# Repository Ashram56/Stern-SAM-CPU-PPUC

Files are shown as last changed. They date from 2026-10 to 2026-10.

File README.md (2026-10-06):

# Stern SAM CPU PPUC

A replacement CPU board for the Stern SAM pinball platform. A Raspberry Pi runs the original game ROM under PinMAME
through the [PPUC](https://github.com/PPUC) stack. An RP2354B on the same board drives the original IO power board bus (J1)
with its PIO, reads the switch matrix, dedicated switches and DIP switches, and can scan the original DMD.

- [docs/ARCHITECTURE.md](docs/ARCHITECTURE.md): architecture, bus timing, pin budget, safety, and open questions.
- [docs/reference/](docs/reference/): Stern SAM manual extracts (IO power driver and CPU/Sound board schematics, backbox,
  playfield, cabinet and coin door wiring).

Background:
- [Tron-Legacy-LE-ROM-Decryption/io/bus](https://github.com/Ashram56/Tron-Legacy-LE-ROM-Decryption/tree/main/io/bus):
  the CPU to IO board bus as the SAM ROM drives it.
- [Stern-SAM-Databus-Analysis](https://github.com/Ashram56/Stern-SAM-Databus-Analysis): J1 pinout and IO board schematic notes.

## Licence

- Firmware and software: GNU GPL v3 ([LICENSE](LICENSE)), matching PPUC.
- Hardware design files: CERN Open Hardware Licence v2, strongly reciprocal ([LICENSE-HARDWARE](LICENSE-HARDWARE)).
- The manual extracts in `docs/reference/` are Stern Pinball's material, kept for reference, and are not covered by
  either licence.

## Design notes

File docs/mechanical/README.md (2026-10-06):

# Original SAM CPU/Sound board: connector and mounting-hole positions

Mechanical reference for laying out the replacement board so it drops into
the original position in the backbox, reuses the original mounting screws,
and lets the existing harness plugs reach their headers.

Source: the component-layout page of the Stern manual
(`docs/reference/Stern_SAM_Manual-CPU_Sound_Board_Schematic.pdf`, page 11,
board 520-5246-00 **Rev G**). That page is a vector drawing, so positions
were read from its path data, not from a scan. `tools/sam_cpu_mechanical.py`
regenerates every file here.

| File | What it is |
|---|---|
| `sam_cpu_520-5246-00_positions.csv` | Every pin, connector body and hole, in mm |
| `sam_cpu_520-5246-00_outline.dxf` | Board edge, holes, connector bodies, pins (layers EDGE, HOLES, CONN, PINS) for import into KiCad |
| `sam_cpu_520-5246-00_annotated.png` | The layout page with the computed coordinates marked |

## Coordinate system

Millimetres, origin at the **top-left corner of the board**, X to the right,
Y down (KiCad convention), seen from the component side with the board as it
hangs in the backbox: J11 power at the top, switch connectors on the left
and bottom edges, USB/serial/display on the right. The DXF uses the same
origin with Y negated (DXF Y points up); import it with the origin at the
top-left corner.

## Scale and confidence

The drawing is uniformly scaled (round holes are round). The scale comes
from connector bodies whose length is fixed by their standard, and six
independent ones agree to within 0.05 %: J1, J2, J3 (n x 3.96 mm KK-396
bodies), J9 (2x10 box header, 33.02 mm), J5 (2x7 box header, 25.40 mm) and
J7 (2x10 pin field, 25.40 mm).

The result lands on round inch values, which is a good sign the scale is
right: the board comes out at **219.06 x 231.76 mm = 8.625 x 9.125 in**,
J9 pins sit at X = 10.16 / 12.70 mm (0.4 / 0.5 in), and every switch
connector pin falls on a 0.025 in grid.

| Quantity | Confidence |
|---|---|
| Board size, hole centres, pin positions **along** each connector | High, about ±0.3 mm (assuming your board matches Rev G) |
| Pin row **across** a KK-396 connector (X of J12/J6/J13, Y of J1/J2/J3) | Medium, ±0.8 mm: the drawing shows the housing, not the pins. I took the centre of the housing without its friction-ramp strip; the row is probably exactly 10.16 mm (0.4 in) from the board edge |
| Hole diameters | Low: the drawing shows the pad/keep-out shapes, not necessarily the drill |

## Mounting holes

Four keyhole slots in the corners plus four round holes. The keyholes open
**upward**: the board is hung on screws through the large circle and drops
down, so the screw shank ends at the top of the slot. That top-of-slot
centre is the screw position to match.

| Hole | Type | Screw X | Screw Y | Notes |
|---|---|---|---|---|
| MH6 | keyhole, top-left | 8.24 | 6.27 | clearance circle centre (8.24, 13.69), Ø10.4; slot 4.4 wide |
| MH1 | keyhole, top-right | 210.16 | 6.27 | circle centre (210.16, 13.69) |
| MH3 | keyhole, bottom-left | 8.24 | 215.17 | circle centre (8.24, 222.59) |
| MH2 | keyhole, bottom-right | 210.16 | 215.17 | circle centre (210.16, 222.59) |
| MH5 | round, top centre | 109.20 | 6.98 | Ø6.3 circle in a 10.2 mm square pad |
| MH4 | round, bottom centre | 97.14 | 222.86 | same |
| MH7 | round, left middle | 8.25 | 116.84 | same |
| MH8 | round, right middle | 210.17 | 116.84 | same |

Keyhole screw spacing: 201.92 mm horizontally, 208.90 mm vertically.

## Left edge (switch matrix and bus)

Pin 1 is at the **bottom** of each connector, numbering upward. Pitch 3.96 mm.

| Conn | Function | Pins | Pin X | Pin 1 Y | Last pin Y | Housing (x0, y0)-(x1, y1) |
|---|---|---|---|---|---|---|
| J9 | Bus to I/O board, 2x10 IDC | 20 | 12.70 odd / 10.16 even | 52.07 (pin 1, 2) | 29.21 (pin 19, 20) | (6.98, 24.13)-(15.87, 57.15) |
| J12 | Upper switch return (columns 9-16) | 10 | 10.03 | 103.51 | 67.87 | (6.73, 65.87)-(14.85, 105.49) |
| J6 | Lower switch return (columns 1-8) | 10 | 10.03 | 163.83 | 128.19 | (6.73, 126.19)-(14.85, 165.81) |
| J13 | Dedicated switches (SW D17-24) | 10 | 10.03 | 208.28 | 172.64 | (6.73, 170.63)-(14.85, 210.26) |

J9 pin 1 is the inner (board-centre side) column, bottom row.

## Bottom edge (dedicated switches and strobes)

Pin 1 is at the **right** end of each connector. Pitch 3.96 mm. Pin row
Y = 221.73 for all three (10.03 mm above the bottom edge).

| Conn | Function | Pins | Pin 1 X | Last pin X | Housing (x0, y0)-(x1, y1) |
|---|---|---|---|---|---|
| J3 | Upper dedicated switch in | 10 | 85.09 | 49.45 | (47.45, 216.91)-(87.07, 225.03) |
| J2 | Lower dedicated switch in | 12 | 151.77 | 108.21 | (106.18, 216.91)-(153.75, 225.03) |
| J1 | Switch drive (row strobes) | 9 | 194.94 | 163.26 | (161.26, 216.91)-(196.92, 225.03) |

## Top and right edges

| Conn | Function | Position |
|---|---|---|
| J11 | Power in, KK-396 1x6, pin 1 at left | pins Y 11.18, X 58.41 to 78.21 |
| J10 | Audio out, KK-396 1x4, pin 1 at left | pins Y 8.76, X 156.19 to 168.07 |
| J15 | USB-B, opens at the right edge | housing (204.22, 60.41)-(219.06, 75.67) |
| J7 | Processor JTAG 2x10 | pin 1 (212.08, 105.40), bottom-right |
| J8 | Xilinx JTAG | outline (205.09, 123.82)-(212.71, 139.06) |
| J5 | DMD display 2x7 IDC | pin 1 (211.44, 164.46), bottom-right; pins 13/14 at Y 149.22 |
| J14 | Serial header | outline (186.17, 157.03)-(202.93, 170.64) |
| J4 | DB9, overhangs the right edge by 6.3 mm | outline (206.78, 173.18)-(225.32, 204.37) |

Every individual pin is in the CSV.

## Finding for the KiCad schematic

The switch connectors J1, J2, J3, J6, J12 and J13 are **KK-396 (3.96 mm,
0.156 in)** headers on the original board, not 2.54 mm. Their drawn bodies
are exactly n x 3.96 mm long, and J12 is 1.2x the length of the 2x10 box
header J9, which only works at 3.96 mm. The existing harness plugs are
0.156 in housings, so the draft 0.1 schematic's
`Molex_KK-254_AE-6410-xxA` footprints for those six connectors need to
become `Molex_KK-396_A-41791-00xx` (J10 and J11 already use KK-396).

## What to measure on the real board

One ruler session confirms everything above:

1. Board width x height. Expected 219.1 x 231.8 mm (8 5/8 x 9 1/8 in).
   If this matches, the scale is confirmed.
2. Board revision printed near the Stern copyright (this data is Rev G).
3. Pin pitch on J12 or J3: pin 1 to pin 10 should be 35.6 mm (3.96 mm pitch).
4. Left edge to the J12 pin centres, and bottom edge to the J1/J2/J3 pin
   centres: expected about 10.0 to 10.2 mm. This settles the medium-confidence
   row position.
5. Screw positions: board corner to the top of each keyhole slot (expected
   8.2 mm in, 6.3 mm down), and what sits in the round holes MH4, MH5, MH7,
   MH8 (screw, plastic standoff or nothing) with its diameter.
6. Optionally, one straight-on photo of the board with a ruler along the
   left and bottom edges, as a record.

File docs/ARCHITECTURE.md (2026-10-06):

# Stern SAM replacement CPU board: architecture

Status: **draft for review**. Nothing here is built yet. Section 11 lists what needs Vincent's answer or a
measurement before the schematic starts.

Sources this document builds on:
- **Bus docs**: [Tron-Legacy-LE-ROM-Decryption/io/bus](https://github.com/Ashram56/Tron-Legacy-LE-ROM-Decryption/tree/main/io/bus)
  (`README.md`, `CPU_BOARD_IO.md` and the CSVs). Register map, ISR schedule and every timing number come from there.
  Re-read on 2026-10-06 after Vincent's update (commit 5ee0e29), which details the switch scan, debounce and fast paths
  (`CPU_BOARD_IO.md` §5) and the DMD page format and scan (§3).
- **J1 schematic reading**: [Stern-SAM-Databus-Analysis](https://github.com/Ashram56/Stern-SAM-Databus-Analysis)
  (`IO board analysis`). Pinout, pull resistors and logic families come from there.
- **Stern SAM manual extracts** in [`reference/`](reference/), shared by Vincent on 2026-10-06 (taken from the Indiana
  Jones manual; the SAM boards are the same across titles apart from minor variants):
  - [IO power driver board schematic](reference/Stern_SAM_Manual-IO_Power_Driver_Board_Schematic.pdf), 520-5249-00 Rev A;
  - [CPU/Sound board schematic, layout and parts](reference/Stern_SAM_Manual-CPU_Sound_Board_Schematic.pdf), 520-5246-00 Rev G;
  - [backbox wiring](reference/Stern_SAM_Manual-Backbox_Wiring.pdf),
    [playfield switch and lamp wiring](reference/Stern_SAM_Manual-Playfield_Switch_Lamp_Wiring.pdf),
    [cabinet and coin door wiring](reference/Stern_SAM_Manual-Cabinet_Coin_Door_Wiring.pdf).
- **PPUC**: [github.com/PPUC](https://github.com/PPUC), read on 2026-10-06: `ppuc/docs/STACK.md`, `ppuc/docs/V2_PROTOCOL.md`,
  `io-boards/src/PPUCProtocolV2.h`, `io-boards/src/IODevices/SwitchMatrix*`, `libppuc/src/PPUC.cpp`.

Statements are tagged **[doc]** (bus docs and schematic notes), **[io-sch]** (IO board schematic), **[cpu-sch]** (CPU/Sound board
schematic), **[ppuc]** (PPUC source), or **[proposal]** (a design choice made here, open to change).

---

## 1. Summary

```
   ┌──────────────────── Raspberry Pi 4 / 5 on the 40-pin header (own HDMI) ──────────────────┐
   │ ppuc-pinmame: PinMAME runs the original SAM ROM, libppuc maps it to boards,              │
   │ libdmdutil drives the display, SDL audio goes out over I2S                               │
   └──────┬──────────────────────┬─────────────────────────┬──────────────────────┬───────────┘
          │ UART (or USB)        │ GPIO: RUN, BOOTSEL,     │ I2S                  │ SPI: DMD frames
          │ (PPUC v2 frames)     │ SWD, IRQ                │                      │ (or ZeDMD, USB)
   ┌──────▼──────────────────────▼──────────┐       ┌──────▼──────┐               │
   │ RP2354B "SAM IO controller"            │◄──────┼─────────────┼───────────────┘
   │  core0: PPUC protocol, config, safety  │       │ DAC + amp   │
   │  core1: real-time scheduler            │       └─────────────┘
   │  PIO0: IO bus master (J9)              │
   │  PIO1: switch matrix + dedicated scan  │
   │  PIO2: DMD scanner (J5), section 8     │
   └───┬──────────────────────────────┬─────┘
       │ 3.3 V ⇄ 5 V buffers          │ input conditioning, 74HC165 chain, strobe drivers
   ┌───▼─────────────┐          ┌─────▼──────────────────────────────┐
   │ J9 → IO board J1│          │ switch matrix (4 x 16), 24         │
   │ (original)      │          │ dedicated switches, DIP switches   │
   └─────────────────┘          └────────────────────────────────────┘
```

The key choices:
1. **The RP2354B looks like a PPUC IO board** [proposal]. It speaks PPUC's v2 protocol, so `ppuc-pinmame` and libppuc run
   unchanged at first. Behind that, instead of driving MOSFETs directly, it translates PPUC's coil, lamp and GI bitmaps into
   writes on the original SAM IO bus (CPU board J9 to IO board J1). PPUC already accepts `platform: SAM` [ppuc], but nothing in PPUC drives a SAM IO board
   yet, so that translation is the new work.
2. **The Pi to RP2354B link is on-board, with no RS485**: a GPIO UART at 1 to 3 Mbaud as the default and native USB as the
   second path, both carrying PPUC v2 frames, plus GPIO lines for reset, flashing and a "switch changed" interrupt
   [proposal]. Section 4 compares them.
3. **PIO does the IO bus cycles, core1 does the timing** [proposal]. The IO power board is only decoders and edge-triggered
   latches with no timing of its own [doc], so every pulse width, lamp slot and blanking gap comes from the RP2354B.
4. **One RP2354B does it all** (Vincent, 2026-10-06): the RP2040's successor with 48 GPIOs and three PIO blocks. PIO0 runs
   the bus, PIO1 reads 64 matrix switches, 24 dedicated switches and 8 DIPs through 74HC165 shift registers, and PIO2 scans
   the original DMD, with 8 GPIOs to spare (section 9.2).
5. **The RP2354B owns safety**: coil pulse limits, the interlock gate, a host-loss timeout and NBRESET [proposal], using PPUC's
   board-owned pulse envelopes [ppuc].

## 2. What the replacement board must provide

From `CPU_BOARD_IO.md` §9 [doc], mapped to who does it here:

| Function | Original SAM CPU board | Here |
|---|---|---|
| IO power board bus (CPU J9 to IO J1): 32 coils + 8 aux coils, 10x8 lamp matrix, GI relay, aux strobes, STATUS | AT91 EBI, 250 µs ISR | RP2354B PIO0 + core1 |
| Switch matrix, 4 strobes x 16 returns (64) in the ROM; 8 strobe drivers on the board | 74LV273 + eight 2N3904 strobes (J1), LM339 returns (J6, J12) [cpu-sch] | RP2354B PIO1 |
| 24 dedicated switches + 8 DIP switches | 74LVC245 inputs on J2, J3, J13 [cpu-sch] | RP2354B PIO1 (same shift chain) |
| Game logic | ROM on the AT91 | PinMAME on the Pi |
| DMD, 128 x 32, 16 shades | Xilinx CPLD scanner, 7 signals on the 14-pin J5 [cpu-sch] | Pi renders, RP2354B PIO2 scans J5, or ZeDMD (section 8) |
| Audio, 24 kHz stereo + volume | PCM1755 DAC, OPA2353, two TDA2030A amplifiers, speakers on J10 [cpu-sch] | Pi I2S + DAC + amplifier (section 8) |
| NVRAM, real-time clock | battery SRAM, DS1302-style RTC | Pi storage (PinMAME `nvram/`), Pi 5 RTC or an I2C RTC |
| LED sign port (9600 baud) | USART1 | optional, a Pi UART |

## 3. The IO bus (CPU board J9 to IO board J1), electrically and logically

### 3.1 Signals [doc] [io-sch]

The bus is a 2x10 header on both boards with the same pinout: **J1 on the IO board, J9 on the CPU board** [cpu-sch]. This
doc and the KiCad schematic follow the original CPU board's reference designators, so on the new board the bus header is
**J9**; J1 on the CPU board is the switch strobe connector (section 5.2). Pin numbers below are the same at both ends.

| J1 / J9 pin | Signal | IO board side (every line also has 100 Ω in series and 22 pF to ground) |
|---|---|---|
| 7, 5, 3, 1, 2, 4, 6, 8 | D0 … D7 (pin 7 = D0, 5 = D1, 3 = D2, 1 = D3, 2 = D4, 4 = D5, 6 = D6, 8 = D7) | 10 k pull-down; 74HC245 input buffer U18; STATUS and AUX_IN buffers drive these pins on reads |
| 12, 14, 16, 18 | A0, A1, A2, A3 | 4.7 k pull-up to 5 V; two 74LS138 (U19, U20) |
| 15 | IOSTB (active low) | 4.7 k pull-up; enables both 74LS138 |
| 13 | NBRESET (active low) | **10 k pull-up to 5 V** (R144), 220 Ω + 470 pF into the watchdog chip (section 3.6) |
| 19, 20 | GND | |
| 9, 10, 11, 17 | not connected | |

Only two of the twenty wires are ground. The new board should keep both, and the ribbon should stay short.

How the IO board uses the data lines [io-sch]:
- **Writes**: U18 is a 74HC245 at 5 V with DIR tied high and its enable tied low, so it is a one-way input buffer that is
  always on. It feeds the 74HCT273 latches (and a 74LS74 for AUX_LMP).
- **STATUS read**: U22, a 74HC245, drives J1 D0-D7 only while the STATUS decode is active. D0 = 20 V interlock, D1 = 50 V
  interlock, D2 = zero cross (through a transistor), D3 = LMP1STAT, D4 = LMP2STAT, **D5-D7 are tied low**.
- **AUX_IN read**: U24, a 74HC245, drives J1 from J3 pins 1-8 (each with 39 k in series and a 1 k pull-up to 5 V).
- Both read buffers drive J1 with **5 V levels**.

Registers (`bus_register_map.csv`) [doc]:

| A3-A0 | Register | Dir | Use |
|---|---|---|---|
| 0 | SOL_A | W | coils 9-16 |
| 1 | SOL_B | W | coils 1-8 |
| 2 | SOL_C | W | coils 17-24 |
| 3 | FLSH_LMP | W | flashers, coils 25-32 |
| 5 | STATUS | R | D0 20 V interlock, D1 50 V interlock, D2 zero cross, D3/D4 lamp driver faults |
| 6 | AUX_DRV | W | data byte for strobed aux boards (J2) |
| 7 | AUX_IN | R | J3 pins 1-8 (unused by the ROM) |
| 8 | LMP_STB | W | lamp strobe lines 0-7 |
| 9 | AUX_LMP | W | lamp strobe lines 8-9 |
| 10 | LMP_DRV | W | lamp drive bits for the active line |
| 11 | aux/GI latch | W | bit 0 GI relay (0 = on), bits 3-7 aux strobes, idle high |

Every latch clocks on the **rising** edge of its decoder output, which follows IOSTB rising [doc].

### 3.2 Level shifting [proposal]

The IO board side is 5 V logic. The RP2354B runs its IO at 3.3 V. Its inputs tolerate 5 V only while IOVDD is powered, and
its outputs are 3.3 V, which the IO board's HC245 does not reliably see as high, so the buffers stay.
- **Address, IOSTB, NBRESET (outputs only)**: one 74AHCT541 (or 74HCT541) at 5 V. Its TTL-level inputs accept 3.3 V and it
  outputs full 5 V. The 74LS138s would also accept 3.3 V directly, but a buffer protects the RP2354B from the 5 V pull-ups and
  from cable faults.
- **D0-D7 (bidirectional)**: one SN74LVC8T245 (A side 3.3 V, B side 5 V). The data inputs on the IO board are a **74HC245 at
  5 V, whose VIH is about 3.5 V**, so driving them straight from 3.3 V is out of spec. The 8T245 also level-shifts the 5 V
  STATUS read down to 3.3 V. Its DIR pin is driven by the PIO program, so direction changes exactly with the bus cycle.
- **What Stern did** [cpu-sch]: the original CPU board drives J9 through two **74LVC245 at 3.3 V** (U25, U26), with 47 pF on
  each line. So 3.3 V drive into the HC245 works in the field, but below its guaranteed threshold. A 74LVC245 (5 V tolerant
  inputs, 3.3 V outputs) is a proven fallback if the 8T245 causes trouble.
- **NBRESET**: open drain, as on the original, which pulls it low with a 2N3904 transistor on net IORESET [cpu-sch] against the IO
  board's 10 k pull-up. An N-MOSFET (2N7002) driven by the RP2354B does the same and needs no level shifting.
- **Power-up state**: both buffers' OE is pulled to "disabled" until firmware enables them. With the buffers off, the IO
  board's own pull-ups hold IOSTB high, so no latch can clock while the RP2354B boots. The NBRESET MOSFET's gate is pulled
  up, so the IO board is held in reset (all outputs off) until the firmware lets go.
- Series resistors (33 to 100 Ω) on the J9 side of every line, for the ribbon cable.

### 3.3 Bus cycle timing

Measured on the original board [doc]: IOSTB low about 100 ns (EBI setting predicts 125 ns), address and data valid when IOSTB
falls and for at least 200 ns after it rises, 650 ns between writes in a burst.

Target for the RP2354B [proposal]: the bus state machine runs with an integer clock divider of 5 at the default 150 MHz, so
one PIO cycle is 33.3 ns with no fractional-divider jitter. That keeps every delay inside the 3-bit delay field left over
by a 2-bit side-set.

| Phase | Time | PIO cycles |
|---|---|---|
| address + data set up before IOSTB falls | ≈ 133 ns | 4 (the `out` and `jmp` instructions) |
| IOSTB low | 167 ns | 5 |
| hold after IOSTB rises | 233 ns | 7 |
| one write, back to back | ≈ 567 ns | 17 |

That is about 1.76 million writes per second, close to the original's 650 ns spacing. The ROM uses about 57,000 accesses per
second in a game [doc], so the bus has about 30 times the headroom we need, even with finer lamp PWM. All timings become
constants in the PIO program and should be checked with a scope against the real IO board (Q4).

Two lessons from the ROM to **not** copy [doc]:
- The ROM writes LMP_STB and AUX_LMP with one 16-bit store, so IOSTB stays low across two addresses. Here every access is
  a separate clean byte cycle.
- The ROM never reads STATUS bits 3-4 (lamp driver faults). We read and report them.

### 3.4 PIO0: the bus master program [proposal]

One state machine executes a stream of 32-bit commands from its TX FIFO:

```
bits  3:0   A3-A0
bits 11:4   D7-D0 (ignored on a read)
bit  12     1 = read (result pushed to the RX FIFO)
bits 31:13  delay after the cycle, in 33.3 ns units (up to ~17 ms)
```

Pins: OUT base = D0, 12 consecutive GPIOs (D0-D7, A0-A3). Side-set: IOSTB and the 8T245 DIR, on two consecutive GPIOs.

```
; sketch: assembles (17 instructions), not yet run on hardware. Clock divider 5 at 150 MHz: 1 cycle = 33.3 ns
.program sam_bus
.side_set 2                         ; side bit 0 = IOSTB, bit 1 = DIR (1 = RP2354B drives the J9 data lines)
.wrap_target
    pull block          side 0b11      ; idle: IOSTB high, 8T245 drives J9
    out pins, 12        side 0b11      ; address + data
    out x, 1            side 0b11      ; read flag
    out y, 19           side 0b11      ; delay after the cycle (these cycles are also the setup time)
    jmp !x write        side 0b11
read:
    mov osr, null       side 0b11
    out pindirs, 8      side 0b11      ; RP2354B releases D0-D7 first
    nop                 side 0b01      ; then the 8T245 turns around and drives the RP2354B side
    nop                 side 0b00 [4]  ; IOSTB low 167 ns: the IO board 245 drives STATUS / AUX_IN
    in pins, 8          side 0b00      ; sample at the end of the strobe
    push noblock        side 0b01 [1]  ; IOSTB high, give the IO board 245 time to let go
    mov osr, ~null      side 0b11 [1]  ; 8T245 drives J9 again
    out pindirs, 8      side 0b11      ; RP2354B drives D0-D7 again
    jmp delay           side 0b11
write:
    nop                 side 0b10 [4]  ; IOSTB low 167 ns
    nop                 side 0b11 [6]  ; IOSTB high: the latch clocks on this edge, data held 233 ns
delay:
    jmp y-- delay       side 0b11
.wrap
```

17 instructions, so about half of PIO0 stays free. The delay field lets core1 (or DMA) queue a whole timed sequence, such as
"blank, wait 24 µs, strobe line 3, drive data", and the PIO plays it with cycle accuracy.

### 3.5 Core1: the real-time scheduler [proposal]

Core1 runs a fixed tick (start with **50 µs**, five times finer than the ROM's 250 µs) and nothing else: no USB, no flash
writes, no interrupts from the host link. Each tick it:

1. **Coils**: evaluates PPUC pulse envelopes and fast-flip rules (`power`, `holdPower`, `holdPowerActivationTime`,
   `minPulseTime`, `maxPulseTime`, `fastFlipSwitch`, `stopSwitch`) [ppuc] against the latest debounced switches, and writes
   SOL_A, SOL_B, SOL_C, FLSH_LMP when they change. The ROM runs its flipper, sling and bumper rules inside the IO tick,
   so a switch reaches its coil 11-17 µs after it is read, plus 0-1 ms for the scan [doc: `CPU_BOARD_IO.md` §5.5]. The
   target here is the same feel: **switch to coil within 1 ms**. Flipper buttons are dedicated inputs, sampled on every
   strobe (125 µs, section 5.4), so they reach the coil in about 200 µs; matrix switches such as the slings in at most
   1.05 ms.
2. **Aux coils 33-40**: AUX_DRV, then the reg 11 shadow with bit 6 low, then with bit 6 high [doc].
3. **Lamp matrix**: section 6.
4. **GI and aux strobes**: always write reg 11 from one shadow byte, as the ROM does [doc], so a strobe pulse never disturbs
   the GI bit.
5. **STATUS**: read every 1 ms. Interlocks gate the coil outputs (section 7); zero cross is time-stamped for the line
   frequency.

Core0 hands core1 new targets through a lock-free double buffer. Core1 never waits on core0.

### 3.6 What the IO board does on its own [io-sch]

**Reset and watchdog.** U23 is a DS1232 supervisor. Its /RST output drives the board-wide **NRESET** net, which goes to the
/MR (clear) pin of **every** output latch: the four coil and flasher 74HCT273s, LMP_STB, LMP_DRV, AUX_DRV, the aux/GI latch,
and the /CLR pins of the 74LS74 for AUX_LMP. While NRESET is low, every coil, lamp strobe, lamp drive and aux output is off and
the GI relay is released. NRESET goes low when any of these happens:

| Trigger | Wiring | Behaviour (DS1232 datasheet values, to verify on the bench) |
|---|---|---|
| 5 V supply low | DS1232 Vcc monitor, TOL set by a 0 Ω option (R146 / R147) | reset while 5 V is under 4.5 V or 4.75 V |
| CPU board pulls **NBRESET** low | J1 pin 13 → 220 Ω → /PBRST, 10 k pull-up, 470 pF | debounced push-button input: must stay low at least ~20 ms to register |
| **Watchdog**: no falling edge on **DRV0** in time | /ST = DRV0, TD tied to ground | timeout 62.5 ms minimum, 150 ms typical, 250 ms maximum |

After a trigger clears, NRESET stays low for at least 250 ms. The yellow LED L18 lights while the board is in reset.

**DRV0 is lamp strobe line 0.** It comes from bit 0 of the LMP_STB latch (U2) and also drives strobe MOSFET Q33. So the
watchdog is fed every time lamp strobe line 0 turns off. The ROM does this every 10 ms, about 6 times faster than the
shortest timeout. If the new board ever stops scanning lamps, the IO board shuts every output off within 62.5 to 250 ms,
which is a useful last line of defence and the reason the scan must start before anything else is enabled.

**Driver speeds**, which set the floor for any finer PWM in phase 2:
- Coils and flashers: STP22NE10L MOSFETs, gate driven through **39 k with 10 nF** to ground. That is an RC of about 0.4 ms,
  so a coil takes several hundred µs to switch fully. Coil hold PWM periods should stay at 1 ms or longer, as the ROM's are,
  and very short pulses will not reach full current.
- Lamp strobes: STP19NE06L, gate through 39 k (no extra capacitor), so tens of µs.
- Lamp drives: VN02N high-side smart switches through 6.8 k. Their status outputs are wired-OR into LMP1STAT and LMP2STAT.
- The ROM's 24 µs blank between strobe lines is in line with these. The exact edge times still need a scope (Q4).

**GI relay**: bit 0 of the aux/GI latch drives a 2N3904 that energises relay RLY1 (FRL264, 20 V coil). The GI strings run
through its normally closed contacts, which is why 0 = GI on.

**Bit order inside the board.** The 74HCT273s are wired with scrambled pin numbers: bus D0 enters chip pin D4, D4 enters D0,
and so on. Following the drawing, SOL_B bus bit 0 drives Q1 (J8 pin 1) and LMP_DRV bus bit 0 drives U10 (J13 pin 1). The
transistor tables in Stern-SAM-Databus-Analysis appear to use the chip's own pin names instead, which gives different
answers (SOL_B bit 0 = Q5, LMP_DRV bit 0 = J13 pin 9). This does not change the firmware, which only needs the ROM's bus bits,
but it matters for wiring and test fixtures (Q16).

## 4. Pi to RP2354B link

### 4.1 What PPUC expects [ppuc]

- Half-duplex RS485 at 115200 baud, 8N1, up to 8 boards, opened by libserialport.
- Frames: `0xA5`, type and flags, next board, sequence, epoch, payload, CRC-16/CCITT.
- The host broadcasts a full OutputState (coil, lamp and GI bitmaps) every 4 ms.
- Switches are host-polled through a token chain: the board answers with a full SwitchState or a SwitchNoChange.
- Config, Setup and Mapping at start-up bind bitmap bits to PinMAME numbers and send pulse settings.

### 4.2 Proposal

No RS485: the RP2354B sits on the same board as the Pi, so the link is either the Pi's GPIO UART or USB (Vincent, 2026-10-06).
Both get wired, and the firmware can speak PPUC frames on either.

| Layer | Choice |
|---|---|
| Primary transport | Pi UART (PL011) ↔ RP2354B UART0, 3.3 V point to point. 115200 at first, so stock libppuc works; then **1 to 3 Mbaud** with a small libppuc change (configurable baud and output interval) |
| Second transport | Pi USB ↔ RP2354B native USB (on-board, no connector). The RP2354B enumerates as a CDC serial port, which libppuc's libserialport opens like any other port, at full-speed USB rates and with no baud setting to change. The same USB port does firmware updates (BOOTSEL mode, `picotool`) |
| Protocol | PPUC v2 frames, unchanged, on either transport. The RP2354B answers as one board (or two board ids, if splitting outputs and switches helps the YAML) |
| Extra GPIO | Pi → RP2354B RUN (reset) and BOOTSEL; Pi ↔ RP2354B SWCLK/SWDIO (flash and debug from the Pi with OpenOCD); RP2354B → Pi IRQ ("switch changed, poll me now") |

Why the UART is the default:
- It is deterministic: no enumeration, no USB stack on the RP2354B, no host-controller scheduling (USB full speed polls in
  1 ms frames), and nothing to re-enumerate if a coil spike glitches the bus.
- At 3 Mbaud it carries 300 KB/s. A SAM OutputState is about 60 bytes (40 coil bits, 80 lamp bits, GI), so even a 1 ms
  output interval uses about 20 % of the link.
- Two pins (section 9.2).

USB costs no GPIO, needs no libppuc change at all, and has more bandwidth, so it is a good choice for bring-up and the
obvious place to go if phase 2 lamp brightness needs more than the UART carries. Which one ships can be decided on the bench
by measuring switch-to-coil latency on both (Q12).

### 4.3 Latency budget [proposal]

| Step | Stock PPUC | Tuned |
|---|---|---|
| switch filter on the RP2354B | 2 scans (2 ms), like the ROM's first stage [doc] | same |
| wait for the host's poll | up to one poll cycle | IRQ line triggers an immediate poll |
| PinMAME reacts | emulated ROM timing (1 ms rule granularity, the ROM's own) | same |
| next OutputState | up to 4 ms | 1 ms |
| RP2354B writes the bus | < 50 µs | same |

Flippers, slingshots and bumpers do not go through the host at all: they run as RP2354B fast-flip rules [ppuc], within
1 ms of the switch (section 3.5), as on the original. Everything else waits on the ROM anyway: its second debounce stage
runs once per 16 ms main-loop pass and holds each edge for 1-10 passes, so rules-level events arrive 1-160 ms after a
closure on the original board too [doc: §5.4].

## 5. Switches

### 5.1 What the ROM reads [doc: `CPU_BOARD_IO.md` §5]

| Register | Content | Rate |
|---|---|---|
| W 0x01100008 | column strobe, one-hot 1 << column, columns 0-3 | every 250 µs |
| R 0x01100000 | 16 returns of the column strobed one tick earlier, 0 = closed | every 250 µs |
| R 0x01100002 | dedicated D1-D16 | every 1 ms |
| R 0x01100004 | low byte D17-D24, high byte the 8 DIP switches (D25-D32) | every 1 ms |
| R 0x01100005 | DIP switches alone | once per 16 ms main-loop pass |

- **Numbering**: switch = column x 16 + row + 1. Columns 0-3 are the matrix (switches 1-64); the dedicated words are
  columns 8 and 9 (switches 129-160 = D1-D32, so the DIPs are 153-160).
- **Settle time**: each column is driven for a whole tick, **246.7 µs median**, before its returns are read. The ROM reads
  first, then writes the next strobe 3.3 µs later.
- **Board revision**: bits 4-6 of 0x01180000. Revision 0 strobes every 2 ticks (2 ms scan), anything else every tick
  (1 ms). PinMAME reports revision 1. The replacement only has to produce the switch states, so this only matters if the
  revision value is emulated.
- **Polarity**: the ROM writes active-high one-hot; the board inverts it through the 2N3904s, so the active strobe pulls
  low [cpu-sch].

### 5.2 The original circuit [cpu-sch]

| Connector | Function | Circuit |
|---|---|---|
| J1, 1x9, key pin 2 ("SWITCH COLUMNS") | **8 strobes** on pins 1 and 3-9 | 74LV273 latch (SWSTB) → eight independent 2N3904 open-collector drivers (1 k base resistors); each line has a 1 k pull-up to +4.5 V and 0.1 µF to ground |
| J6, 1x10, key pin 4, and J12, 1x10, key pin 5 ("SWITCH ROWS") | **16 returns**, 8 per connector, plus a ground pin each | each return: series diode (SMT4148) from the connector, 220 Ω, 1 k pull-up to **+4.5 V**, 0.1 µF, into an **LM339** comparator against VREF (3.3 k / 3.3 k divider of 4.5 V, about 2.25 V, 22 µF); comparator outputs pulled up to 3.3 V (10 k) and read through 74LVC245s |
| J2 (1x12, key 5), J3 (1x10, key 3), J13 (1x10, key 2) | **24 dedicated inputs**, 8 per connector, plus ground pins | switches to ground; 1 k pull-up to +4.5 V (the parts list says 1.5 k), 39 k series, 47 pF, read through 5 V-tolerant 74LVC245s |
| SW1 | 8 DIP switches | on the board, 1 k pull-ups to 3.3 V |

+4.5 V is the 5 V rail through a diode (D10). So the matrix runs at about 4.5 V, not 12 V: a closed switch pulls its return
low through the playfield diode, the return diode and the active strobe transistor. Stern's manual describes it as a
"4 x 16 matrix of Switch Drives and Switch Returns" plus a "2 x 16" dedicated matrix that includes the 8 DIP positions.

The board has **8** strobe drivers, but the ROM scans 4 and the Indiana Jones playfield wiring diagram only uses switch
drives 1-4. Tron LE also scans only 4 (Q15); its fiber optic ramp tubes are driven from the IO board's aux strobes, not
from these switch strobes (section 6.3).

### 5.3 Hardware [proposal]

- **Returns**: copy the original front end (1 k pull-up to 4.5 V, 220 Ω + 0.1 µF, LM339 against 2.25 V). The LM339's
  open-collector outputs, pulled up to 3.3 V, feed the shift registers directly. It is cheap, proven on these harnesses and
  immune to the ground offsets of a long cable.
- **Dedicated switches**: the same 1.5 k pull-up and 39 k / 47 pF filter, then either an LM339 stage like the returns or a
  divider into the 3.3 V shift registers.
- **Shift chain**: 48 inputs (16 returns + 24 dedicated + 8 DIP) through **six 74HC165** at 3.3 V.
- **Strobes**: **8** open-collector outputs, like the original, from a 74HC595 that shares the shift clock (below) and drives
  8 low-side transistors or a ULN2803-class array.

Cost: 5 RP2354B pins (shift clock, 165 load, 165 data, 595 data, 595 latch) for 48 inputs and 8 strobes.

### 5.4 PIO1 scan program [proposal]

One state machine loops forever:
1. Pulse the 165 load line, then clock 48 bits at about 10 MHz (about 5 µs). On every clock it does `in pins, 1` from the 165
   chain and `out pins, 1` to the 595, so the strobe pattern for the *next* strobe ends up in the 595 during the last 8 clocks.
2. Pulse the 595 latch: the next strobe turns on.
3. Push two words (returns for the strobe that was active, plus the dedicated and DIP bits) and wait the settle time.

**Settle time sets the scan rate, not the shifting.** The original front end has a 1 k pull-up and 0.1 µF on every return
and every strobe line [cpu-sch]: an RC of 100 µs, so a return released by an opening switch takes about 70 µs to climb
back past the LM339's 2.25 V threshold. The ROM allows 247 µs [doc]. Default here: **125 µs per strobe**, so 8 strobes
take 1 ms, the same full-scan time as the ROM. Shortening it means reducing those capacitors and checking on the bench.
With 4 strobes (Q15) the same 1 ms gives 250 µs per strobe, exactly the original.

A DMA channel copies the words into a ring in RAM. Dedicated switches are sampled on every strobe (every 125 µs), 8 times
more often than the ROM reads them, which is what keeps the flipper buttons fast (section 3.5).

This follows the structure of PPUC's `SwitchMatrix.cpp` and `SwitchMatrixPIO/*.pio` [ppuc] (one SM walks the strobes, a
second reads the returns, "two identical scans" filter), but PPUC's code reads at most 8 returns on direct GPIOs and caps at
8 rows. Our 16 returns through a shift chain need a new program either way.

### 5.5 Debounce and reporting [proposal]

The ROM debounces in two stages [doc: §5.3-5.4]: in the IO tick, a change must show on 2 consecutive scans (1 ms apart);
then once per 16 ms main-loop pass, each switch must hold for a per-switch count of passes (1-10, from the switch
descriptors) before the rules see it. On Tron, flipper EOS and slam tilt use 0 / 0, slings 1 / 4, bumpers 1 / 2, ramps
1 / 9, DIPs 10 / 10 (close / open).

PinMAME runs that same ROM code on the switch states we report. So the board must **not** add its own long debounce, or
the two would stack:
- Core0 diffs each scan against the last and reports a change once it is seen on **2 consecutive scans** (PPUC
  `standard`). This only filters electrical glitches; the ROM's stage 2 still does the real debounce.
- Fast-flip rules on core1 use PPUC's `fastFlip` mode (a close counts at once, an open must hold) [ppuc], so a flipper
  fires on the first closed sample.
- Changes go into the PPUC switch queue (32 deep) [ppuc] and raise the IRQ line to the Pi.
- Switch numbering follows PinMAME's SAM numbers (section 5.1), so libppuc's mapping is a straight pass-through. The
  dedicated switch PinMAME numbers are already listed in `Tron-Legacy-LE-ROM-Decryption/rom_data/states/dedicated_switches.csv` [doc].

## 6. Lamps

### 6.1 Matrix scan, phase 1 (ROM-compatible) [proposal]

Reproduce what the ROM does [doc]:
- 10 strobe lines (LMP_STB bits 0-7, AUX_LMP bits 0-1) x 8 drive bits (LMP_DRV).
- For each line: LMP_DRV = 0, LMP_STB = 0, AUX_LMP = 0 (blank), wait 24 µs, strobe the next line, then LMP_DRV = its data.
- 1 ms per line, 10 ms frame.
- Lamp state comes from PPUC's lamp bitmap (on/off) [ppuc].

**The IO board's watchdog is fed by lamp strobe line 0** [io-sch, section 3.6]: a falling edge on DRV0 at least every 62.5 ms
(worst case of the DS1232), or every output on the IO board is cleared. The scan therefore runs from the moment the RP2354B
enables the bus, whether or not the Pi is connected. Stopping the scan is a deliberate way to shut the IO board down.

### 6.2 Brightness, phase 2 [proposal]

The bus docs §10 [doc] show the existing IO board can do much finer lamp PWM than the ROM's 4 levels, without hardware
changes: at the start of each line slot, write every lamp that should be on, then rewrite LMP_DRV as each lamp's on-time
ends ("edge-sorted PWM", at most 9 writes per slot). With the PIO delay field this is just a sorted list of commands per
slot, built by core1.

PPUC's OutputState carries lamps as bits [ppuc], so dim levels (the ROM's 1/3 and 2/3 planes, and fades) are lost today.
Getting them needs either a PPUC protocol extension (a lamp brightness payload) or a dedicated "lamp levels" frame type
negotiated through the Admin frame. Proposed for phase 2, after the board works with on/off lamps.

### 6.3 Strobed aux boards (Tron LE ramp tubes and similar) [proposal]

Some SAM games hang extra boards off AUX_DRV and the reg 11 strobes [doc]. Tron LE uses ESTB and DSTB for the two RGB ramp
tubes, driven by the ROM with 4-bit BCM [doc], and PinMAME exposes them as lamps 101-106 [doc: `io/README.md`, PinMAME
`sam.c`]. The firmware gets a generic "aux latch device" configured per game: strobe bit, which AUX_DRV bits, which PPUC lamp
numbers. Phase 1 drives them on/off; with phase 2 brightness they get BCM or edge-sorted PWM like the matrix.

## 7. Safety [proposal]

| Risk | Mitigation |
|---|---|
| RP2354B boots or crashes with coils latched on (the latches hold their last value [doc]) | J9 buffers disabled at reset (IOSTB pulled high by the IO board). NBRESET held low (gate pull-up on the open-drain MOSFET) until the firmware is configured: on the IO board this clears every output latch through the DS1232 [io-sch]. RP2354B hardware watchdog enabled; its reset path disables the buffers and asserts NBRESET. |
| RP2354B hangs with the bus enabled | The lamp scan stops, so the IO board's own watchdog clears every output within 62.5-250 ms [io-sch]. |
| Pi hangs or the link drops | No valid OutputState for 50 ms → all coil registers written 0, fast-flip rules disabled, lamps keep scanning. For a hard stop, assert NBRESET for at least 20 ms: the IO board then clears everything and holds it for at least 250 ms. PPUC has the same idea host-side [ppuc]. |
| Host asks for a coil too long | PPUC board-owned envelopes: `maxPulseTime` on every coil, enforced in core1 even for host-driven coils [ppuc]. |
| High voltage missing or door open | STATUS interlock bits gate coil outputs, like the ROM's mask at 0x3b984 [doc]. No coil may fire without both interlocks (Vincent, Q7). |
| Lamp driver fault | STATUS bits 3-4 reported to the host as switches (the ROM ignores them [doc]). |
| Bus contention during STATUS reads | 8T245 DIR flips before IOSTB falls and back after it rises (section 3.4). |

## 8. Display and sound [proposal]

These are on the original CPU board, so the replacement has to provide them, but they belong to the Pi side, not the RP2354B.

- **Display: both options stay available** (Vincent, Q8). The board provides the original-DMD driver, and ppuc-pinmame can
  drive a ZeDMD panel at the same time or instead, chosen in `ppuc.ini`:
  - **A. Keep the original 128x32 DMD.** The display cable is the 2x7 J5: the 7 signals on the odd pins, every even pin
    ground. They come from the XC95144XL CPLDs through a 74HCT245 at 5 V (U55) [cpu-sch]. In buffer order: pin 1 DE,
    3 ROWDATA, 5 ROWCLK, 7 COLLATCH_A, 9 PIXCLK, 11 SDATA, 13 COLLATCH_B (read from the drawing; confirm with a meter before
    relying on it). The display's high voltage comes from its own Display Power Supply board (520-5138-00), not the CPU board.
    What the original does [doc: `CPU_BOARD_IO.md` §3]:
    - The ROM draws into 30 pages of 128 x 32 bytes (low nibble shade 0-15, high nibble mask) and flips a foreground and a
      background page register once per 16 ms pass, unsynchronised to the scan. The FPGA mixes them:
      `pixel = (bg & mask) | (fg & ~mask)`. **PinMAME already does the paging and the mix**, so the Pi only ever sends the
      finished 4-bit 128x32 frame (2 KB). The board does not need page memory or the mixer.
    - The FPGA scans by itself at **62.67 Hz**: 32 rows one at a time, 12 slots of 41.55 µs per row, the 4 shade planes shown
      for 1, 2, 4 and 5 slots (13 distinct levels). Sending 128 dots in one slot needs a dot clock of at least 3.1 MHz.

    Here [proposal]: **PIO2 on the same RP2354B** generates the 7 J5 signals through a 74HCT245 at 5 V, as the original
    does. The Pi sends frames over SPI (3 pins); core0 double-buffers them and swaps **only at frame start**, so there is no
    tearing whatever the original did. A DMA channel feeds the PIO, so the scan costs no CPU time. Default: copy the
    original 1/2/4/5 weighting so games look as they did, with linear 1/2/4/8 (16 levels in 15 slots) as an option. The dot
    clock, latch and row-clock timing within a slot are not in the ROM and need a scope on the original J5 (Q18); until
    then PPUC's `dmdreader` firmware [ppuc], which decodes SAM DMD signals, documents that timing from the receiving side.
  - **B. An LED panel** driven by ZeDMD, which ppuc-pinmame supports today through libdmdutil [ppuc] over USB. No new
    firmware. It is also the display for bring-up, before the J5 driver works.
- **Sound**: PinMAME emulates the SAM sound system and ppuc-pinmame plays it through SDL [ppuc]. The original amplifier is on
  the CPU board [cpu-sch]: a PCM1755 DAC (I2S, with the 3-wire volume control), an OPA2353 buffer and **two TDA2030A power
  amplifiers on ±12 V**, with the speakers on the 1x4 J10 (pin 1 amplifier U50, pin 2 amplifier U51, pins 3-4 ground) [cpu-sch].
  The DAC runs from its own +5 V (LM340T-5 from +12 V). The new board does the same: Pi I2S → a stereo DAC → two
  amplifiers on J10, pin-compatible with the cabinet harness. The volume buttons are dedicated switches handled by the ROM,
  so volume stays the ROM's job.

## 9. Hardware

### 9.1 Pi choice

Vincent (Q10): whatever is available, most likely a **Pi 4**. A Pi 4 runs PinMAME's ARM7 SAM core comfortably (inferred,
to confirm with a benchmark).

**Decided for the prototype (Vincent, 2026-10-06): a standard Pi on its 40-pin GPIO header** (J21, section 9.4). The Pi
keeps its own native HDMI output, so no high-speed video signals are routed on this PCB; the same goes for its USB and
Ethernet. Every signal the board needs is on the header: UART, SPI (DMD frames), I2S (audio), and plain GPIOs for RUN,
BOOTSEL, SWD and IRQ. The native-USB link to the RP2354B (section 4.2) goes Pi USB-A to the board's USB-C (J19) with a
short cable, because USB is not on the header.

A Compute Module carrier is out of scope for now. Keeping to header signals means a CM4 or CM5 carrier stays a layout
change rather than a redesign, but it would bring HDMI and USB routing onto the board, which is exactly what this choice
avoids.

### 9.2 RP2354B and pin budget [proposal]

Vincent chose the **RP2354B** (2026-10-06): the RP2350B die with 2 MB of flash stacked in the 80-pin QFN, so there is no
external QSPI flash part. Against the RP2040 it has 48 GPIOs instead of 30, 3 PIO blocks (12 state machines) instead of 2,
two 150 MHz cores (Cortex-M33 or RISC-V) and 520 KB of SRAM. The pico-sdk and the Arduino earlephilhower core support
it, so PPUC `io-boards` code and the PIO programs carry over. Note: the Pico 2 board uses the 30-GPIO RP2350A; a bench
board needs the B variant.

One RP2350 constraint shapes the layout: **each PIO block sees a window of 32 consecutive GPIOs** (GPIO 0-31 or 16-47).
So the bus sits low for PIO0, the DMD high for PIO2, and the switch chain in the overlap.

| GPIO | Function | Count | User |
|---|---|---|---|
| 0-11 | J9 D0-D7 + A0-A3 (consecutive, for `out pins, 12`) | 12 | PIO0 |
| 12-13 | IOSTB, 8T245 DIR (side-set, consecutive) | 2 | PIO0 |
| 14 | NBRESET | 1 | core1 |
| 15 | J9 buffer OE | 1 | core1 |
| 16-20 | Switch chain: shift clock, 165 load, 165 data, 595 data, 595 latch | 5 | PIO1 |
| 21-27 | J5 DMD: DE, ROWDATA, ROWCLK, COLLATCH_A, PIXCLK, SDATA, COLLATCH_B | 7 | PIO2 (window 16-47) |
| 28-30 | SPI1 from the Pi: RX, CSn, SCK (DMD frames) | 3 | SPI1, peripheral mode |
| 32-33 | UART0 TX, RX to the Pi | 2 | UART0 |
| 34 | IRQ to the Pi | 1 | core0 |
| 35-36 | GI dimmer header: GI_PWM, GI_SPARE (10.2) | 2 | PWM |
| 31 | Coin door memory protect (J2 pin 10) | 1 | core0 |
| 40-41 | 5 V and 12 V supply monitors (ADC) | 2 | ADC |
| 42 | status LED | 1 | core0 |
| **Total** | | **40 of 48** | |

That leaves 8 GPIOs (37-39, 43-47, including 5 ADC inputs) for later. The exact function-select numbers (SPI1 and
UART0 pins) are to be checked against the RP2350 datasheet's GPIO function table when the schematic starts. RUN, SWD and
the BOOTSEL (QSPI_SS) pin are dedicated, wired to Pi GPIOs.

Erratum RP2350-E9: an input pad with its internal pull-down enabled can latch at about 2 V. Every input here is driven
by a push-pull buffer (8T245, 74HC165, the Pi), so nothing relies on the internal pull-downs; external resistors are used
where a defined idle level is needed.

### 9.3 Power [proposal]

The CPU board is fed from IO board connector **J16** (15-pin KK156) [io-sch]. On the CPU board it arrives on **J11, 1x6**:
pin 1 +5 V, pin 3 -12 V, pin 6 +12 V, pins 2, 4, 5 ground, each through a ferrite bead and 47 µF [cpu-sch]. On board, an
LT1086 makes 3.3 V from 5 V and an LT1503 makes the AT91 core voltage. J16 on the IO board:

| J16 pin | Rail |
|---|---|
| 1 | -12 V |
| 2, 3 | +12 V |
| 4-8 | +5 V |
| 9-13, 15 | GND |
| 14 | key |

The +5 V comes from an **LM338K (5 A) on the IO board**, which also powers the IO board's own logic. ±12 V come from a bridge
and capacitors on the IO board.

**Vincent (Q14): power is plentiful and will be provided externally; both sources must be supported** (follow-up:
"provide both option to use external or the regular IO board"). So the new board:
- has **two +5 V inputs**: the J11 +5 V pin from the IO board (as on the original CPU board), and an **external supply
  connector** sized for a Pi 4 (3 A) plus the RP2354B, the switch inputs and the DMD buffer, with margin;
- feeds them through an **ideal-diode power mux** that prefers the external input when it is present and falls back to
  J11 otherwise. The KiCad draft (PR #2) uses **two LTC4412 ideal-diode controllers with AO3401A P-MOSFETs**: the external
  path is always on, and `EXT_PRESENT` turns the J11 path off. The two 5 V supplies are never tied together, so neither
  back-feeds the other. A TI TPS2121 (4.5 A integrated mux) does the same in one part and was the first choice, but KiCad's
  libraries have no symbol for it, so it would need a custom symbol and footprint; it stays an option for the PCB. A jumper
  can force J11-only or external-only for debugging [proposal];
- keeps J11 (same pinout as the original) for **±12 V for the two audio amplifiers** and as the common ground with the IO
  board, whichever +5 V source is used;
- needs a solid ground between the external supply, J11 and J9, because the bus cable itself has only two ground wires;
- makes 3.3 V for the RP2354B with its own regulator. A supervisor holds the RP2354B in reset until 3.3 V and 5 V are
  stable.

Caveat for the IO-board source: the LM338K is rated 5 A and also powers the IO board's own logic, and the original CPU
board drew well under that. A Pi 4 can pull up to 3 A, and the drop along the J16/J11 harness can push it below its
4.63 V undervoltage threshold. With J11 power, a Pi 3 or a capped Pi 4 load is the safe choice; bring-up should
measure the 5 V at J11 under load before relying on it [proposal].

### 9.4 Connectors [proposal]

Reference designators follow the original CPU/Sound board 520-5246-00, so the cabinet harness labels still match: J1
switch strobes, J2 / J3 / J13 dedicated switches, J5 DMD, J6 / J12 switch returns, J9 IO bus, J10 speakers, J11 power
from the IO board. New connectors start at J17 (as in `hardware/kicad/README.md`, PR #2):

| Ref | Function |
|---|---|
| J17 | external +5 V input (9.3) |
| J18 | GI dimmer header: +5 V, GND, GI_PWM, GI_SPARE (10.2) |
| J19 | USB-C to the Pi |
| J20 | SWD to the RP2354B |
| J21 | Raspberry Pi 40-pin header (9.1) |

## 10. Software

### 10.1 RP2354B firmware [proposal]

- Base: PPUC `io-boards` (PlatformIO, Arduino earlephilhower core with RP2350 support, pico-sdk PIO calls) [ppuc], as a new board type
  ("SAM_CPU"), so the protocol code, config parser and pulse envelope logic are reused rather than rewritten. The firmware is
  GPLv3, matching PPUC (Q11); hardware design files are CERN-OHL-S v2. The manual extracts in `reference/` are Stern's
  material and are not covered by either licence.
- New code: the IO bus PIO program and scheduler (core1), the 165-chain switch scanner, the SAM lamp matrix, aux latch
  devices, the STATUS reader, the safety rules above, and the DMD scanner (PIO2 + DMA, frames over SPI1).
- Core split: PPUC io-boards runs the bus and switches on core0 and LED effects on core1 [ppuc]. Here core1 becomes the SAM
  real-time scheduler instead, and LED effects (unused on SAM) are compiled out.

### 10.2 Pi side [proposal]

- `ppuc-pinmame` with a SAM game folder: `io-boards.yaml` with `platform: SAM`, the coil list (PinMAME numbers 1-32, aux
  33-40), 80 lamps, 64 matrix switches, the dedicated switches, plus pulse and fast-flip settings per coil. Starting
  values come from the ROM captures [doc: §5.5]: flipper 40.5 ms full power, then hold 1 ms on / 11 ms off; slingshot
  33.6 ms; bumper 48.7 ms.
- A generator script that builds that YAML from the ROM data already extracted for Tron (`rom_data/io/coils.csv`,
  `io/bus/lamp_matrix_map.csv`, `dedicated_switches.csv`), so other SAM titles follow the same route.
- libppuc changes, small and upstreamable: configurable baud rate and output interval; later the lamp brightness
  extension (section 6.2).
- GI (Vincent, Q17): **controlled by the PPUC controller**, which may be PinMAME or something else, and potentially PWM.
  libppuc's "GI forced on for non-WPC platforms" [ppuc] has to give way to a configurable mapping. Vincent's follow-up
  settles how:
  - **The relay stays on/off.** GI is an ordinary PPUC output mapped to bit 0 of the aux/GI latch, driving RLY1 (an
    FRL264, section 3.6). The firmware enforces a minimum switching interval on that bit, so PWM never reaches the relay.
  - **Optional solid-state GI dimmer board, wired after the relay.** It sits in series with the GI feed downstream of the
    RLY1 contacts, so the relay remains the master on/off and the stock behaviour is untouched when the board is absent.
    GI on SAM is low-voltage AC, so the dimmer does phase-angle control (back-to-back MOSFETs with its own zero-cross
    detection) [proposal].
  - **Link to the CPU board** (IO to be defined; "whatever is available"). Default [proposal]: a small 4-pin header,
    J18: +5 V, GND, GI_PWM, GI_SPARE. GI_PWM is one RP2354B GPIO producing a fixed-frequency PWM whose duty cycle is the
    brightness; the dimmer board takes it through an optocoupler, filters it and sets its phase angle locally, so the
    CPU board never needs the AC zero crossing and stays isolated from the GI circuit. GI_SPARE is a second
    GPIO, reserved for a zero-cross or fault signal back, or for a second GI channel. Both come from the spare GPIOs in
    9.2. In PPUC terms, GI brightness is a PWM output whose value goes to GI_PWM while the on/off state still goes to the
    relay.

### 10.3 Rejected alternative: raw bus pass-through

Hook PinMAME's emulated SAM IO handlers and forward every register write to the RP2354B, which replays them on the IO bus. It would
reproduce the ROM exactly, but it needs about 57,000 accesses per second [doc] with emulator timing jitter on a non-real-time
host, it bypasses PPUC's logical model and safety envelopes, and it keeps the ROM's coarse lamp and coil timing. Kept only as a
debug mode for comparing the two paths on a logic analyzer.

## 11. Open questions for Vincent

Answered so far:

| # | Question | Answer | Where |
|---|---|---|---|
| Q1 | CPU/Sound board schematic | Shared as PDF; now in `reference/` | 5.2, 8, 9.3 |
| Q2 | Switch input conditioning | 4.5 V pull-ups, LM339 comparators on the returns, 8 independent 2N3904 open-collector strobes | CPU schematic; 5.2 |
| Q3 | Bus pins 9, 10, 11, 17, 19 (IO J1 / CPU J9), and CPU board power | 9, 10, 11, 17 not connected; 19, 20 ground. Power from IO board J16 (+5 V, ±12 V) | IO schematic; 3.1, 9.3 |
| Q4 | Scope the bus and a coil gate? | Stay with the conservative default timings | 3.3 |
| Q5 | What feeds the IO board watchdog | DS1232: falling edge on lamp strobe line 0 (DRV0) at least every 62.5 ms worst case | IO schematic; 3.6 |
| Q6 | Does NBRESET clear the latches? | Yes: NBRESET → DS1232 /PBRST → NRESET → /MR of every output latch; at least 250 ms reset | IO schematic; 3.6, 7 |
| Q7 | Coils allowed without 50 V | None | 7 |
| Q8 | Original DMD or ZeDMD | Keep both options available | 8 |
| Q9 | Audio amplifier on the CPU board? | Yes: PCM1755 + two TDA2030A on ±12 V, speakers on J10 | CPU schematic; 8 |
| Q10 | Pi model | Whatever is available, likely Pi 4. Prototype plugs in through the 40-pin GPIO header and keeps the Pi's own HDMI; no CM4 for now | 9.1 |
| Q11 | Licences | Yes: GPLv3 for firmware and software (`LICENSE`), CERN-OHL-S v2 for hardware (`LICENSE-HARDWARE`) | 10.1 |
| Q12 | The high speed bus | GPIO or USB, no RS485. Both wired; UART default | 4.2 |
| Q14 | Power budget | Plenty; support both an external supply and the IO board (J11) | 9.3 |
| Q19 | Interface MCU | RP2354B instead of RP2040 | 9.2 |
| Q17 | GI control | By the PPUC controller. Relay stays on/off; optional solid-state dimmer board after the relay, wired to a CPU board header (IO to be defined, default one PWM GPIO + one spare) | 10.2, 9.2 |

Still open:

| # | Question | Status | Default meanwhile |
|---|---|---|---|
| Q13 | Which SAM titles come first besides Tron LE? | To be defined | Tron LE first |
| Q15 | Do any SAM games use switch strobes 5-8? | Not Tron LE: its ROM sizes the matrix at 65 switch numbers, so 4 columns [doc: `CPU_BOARD_IO.md` §5.1]. The fiber optic ramp tubes are not switch strobes; they hang off the IO board's aux strobes ESTB/DSTB on IO J3 (section 6.3). Other titles unknown: the ROM's scan code handles up to 8 columns | Drive all 8; per-game strobe count in the config |
| Q16 | Continuity check of the 74HCT273 bit-to-pin mapping (section 3.6) against the Stern-SAM-Databus-Analysis tables | Vincent will check | Firmware uses the ROM's bus bits, so nothing waits on it |
| Q18 | Scope the original J5 DMD signals: dot clock, latch and row-clock timing within a slot, and whether page flips take effect at frame start | New, from the Tron repo update (`CPU_BOARD_IO.md` §3.4) | PinMAME's 62.67 Hz / 41.55 µs figures and `dmdreader`'s timing; swap buffers at frame start |

## 12. Proposed plan

1. **Bench bring-up of the IO bus**: an RP2350B dev board (for example Pimoroni PGA2350; not a Pico 2, which has the
   30-GPIO RP2350A) + the two level shifters on a prototype, the PIO bus program, and a
   logic analyzer next to a capture from the original CPU board. Coil power off.
2. **Lamp matrix + watchdog** running standalone on the IO board, with a test pattern.
3. **Switch scanner** on a prototype input stage, measuring how short the per-strobe settle time can go (section 5.4).
4. **PPUC integration**: the RP2354B as a PPUC board over UART at 115200, Tron LE YAML, PinMAME running the ROM on the Pi.
   First full game.
5. **Coils with safety**: fast-flip rules, envelopes, interlocks, host-loss timeout. Then coil power on.
6. **Speed-up**: 1-3 Mbaud, 1 ms outputs, IRQ-driven polling.
7. **Display and sound**: ZeDMD over USB first, then the PIO2 J5 scanner for the original DMD after scoping J5 (Q18);
   the audio amplifier copies the original (section 8).
8. **PCB** in the SAM CPU board footprint.
9. **Phase 2**: lamp brightness, aux tube PWM, other SAM titles.

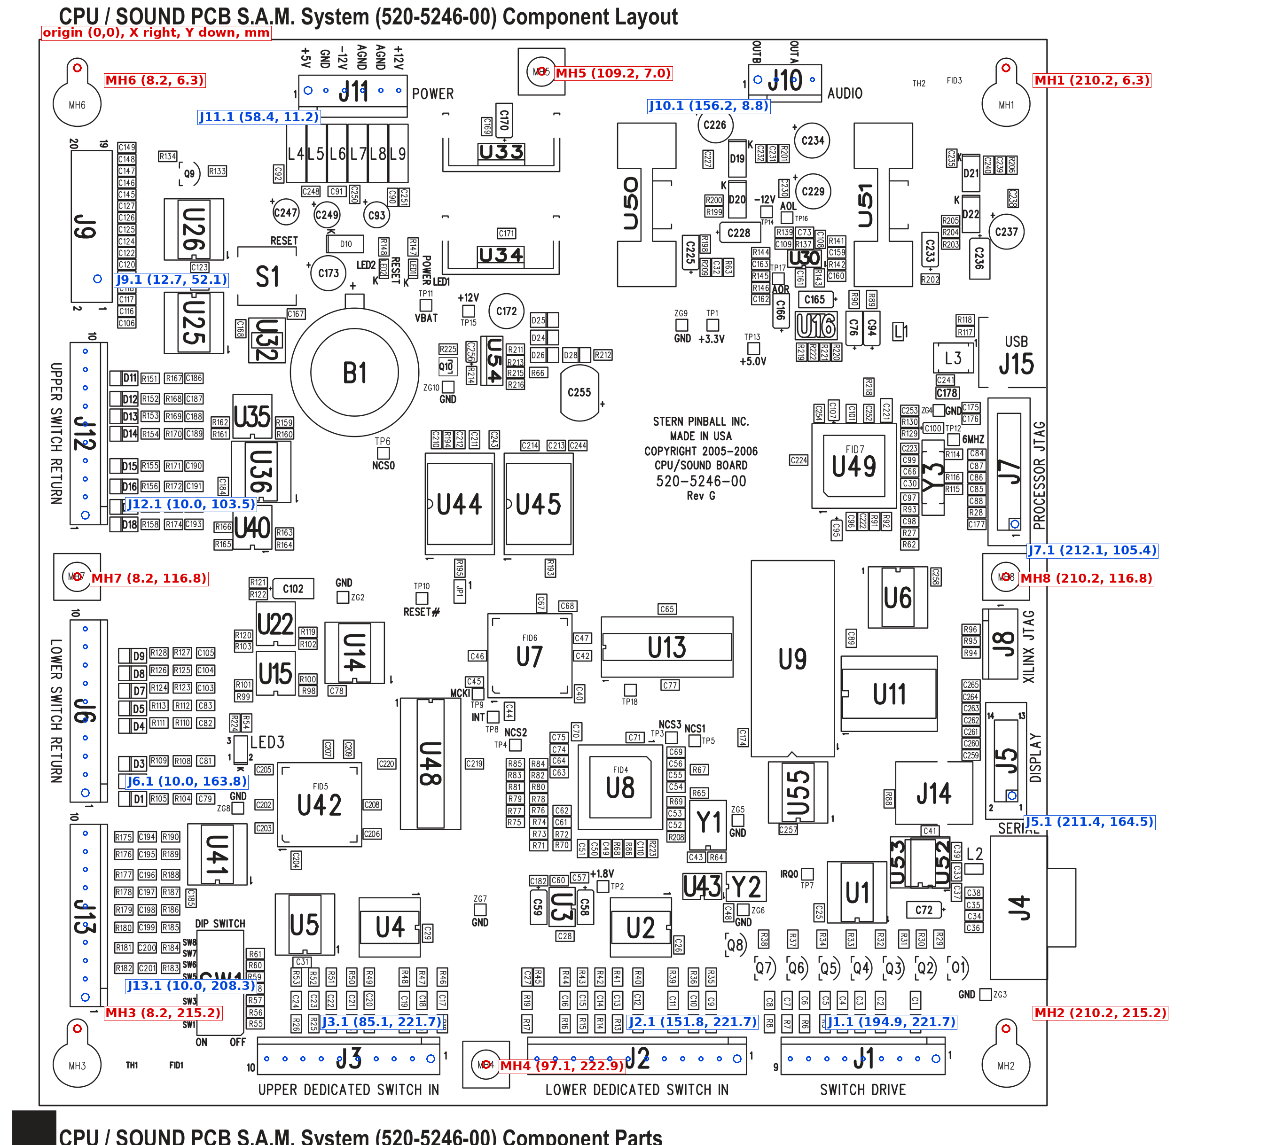
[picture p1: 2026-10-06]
docs/mechanical/sam_cpu_520-5246-00_annotated.png

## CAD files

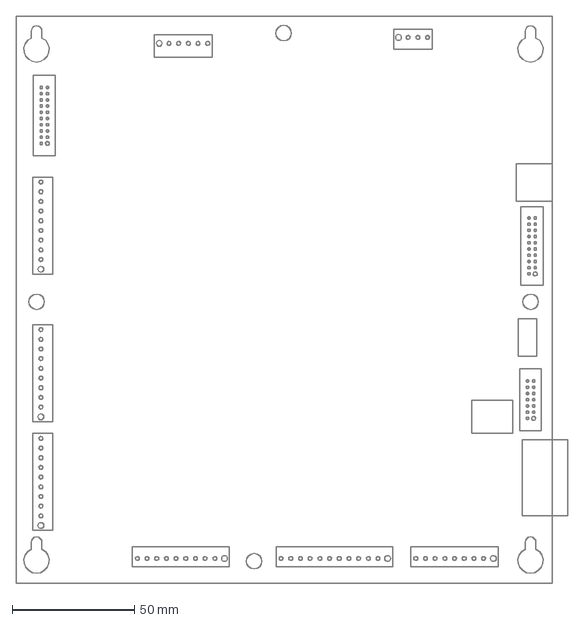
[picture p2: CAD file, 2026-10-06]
docs/mechanical/sam_cpu_520-5246-00_outline.dxf
225.3 x 231.8 mm

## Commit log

2026-10-06 docs: architecture for a Pi + RP2040 SAM CPU replacement on PPUC
    Covers the J1 bus electrical interface and level shifting, a PIO bus
    master program, the core1 real-time scheduler, the Pi to RP2040 link
    (PPUC v2 frames over UART), switch scanning through a 74HC165 chain,
    the lamp matrix and IO board watchdog, safety, display and sound,
    the RP2040 pin budget, and open questions.
    Claude-Session: https://claude.ai/code/session_01NKLRMj2a7Jym9GhYtjGVEP
2026-10-06 docs: fold in the IO board schematic, CPU board schematic text and the GPIO/USB link
    - J1 pinout confirmed (9, 10, 11, 17 NC; 19, 20 GND), NBRESET has a 10 k
    pull-up and goes to a DS1232; read buffers drive J1 at 5 V.
    - New section 3.6: the DS1232 watchdog is fed by lamp strobe line 0
    (TD = GND, 62.5 ms minimum timeout) and NRESET clears every output latch;
    coil gate RC (39 k / 10 nF) limits PWM; 74HCT273 pin scramble.
    - Switches: 4.5 V pull-ups, LM339 returns, 8 open-collector strobes;
    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
2026-10-06 docs: add Stern SAM manual extracts and fold in the CPU/Sound schematic
    Adds the IO power driver and CPU/Sound board schematics plus the backbox,
    playfield and cabinet wiring pages under docs/reference/, renamed from
    the Indiana Jones manual to Stern_SAM_Manual-<section>.pdf.
    From the CPU/Sound drawings: 8 independent strobe drivers on J1, 16
    returns on J6/J12 with LM339s, 24 dedicated inputs on J2/J3/J13, DMD
    pinout on J5 (signals on odd pins), speakers on J10, power input J11.
    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
2026-10-06 docs: apply Vincent's answers and add licences
    External +5 V supply, Pi 4/CM4, both display options (ZeDMD first),
    GI under PPUC control (relay caveat for PWM), no coil without both
    interlocks. Add GPLv3 (firmware) and CERN-OHL-S v2 (hardware).
    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
2026-10-06 docs: support +5 V from either an external supply or the IO board
    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
2026-10-06 docs: GI stays on/off via relay, optional solid-state dimmer board after it
    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
2026-10-06 docs: RP2354B, switch scan and DMD details from the updated Tron bus docs
    - Interface MCU is now the RP2354B: 48 GPIOs, PIO2 scans the original DMD,
    PIO 32-GPIO windows shape the pin map, bus clock 150 MHz / 5.
    - Switch scan settle set to 125 us per strobe (1 k / 0.1 uF front end),
    1 ms full scan as the ROM; light 2-scan filter since PinMAME runs the
    ROM's own two-stage debounce; switch-to-coil target 1 ms.
    - DMD: PinMAME supplies mixed frames; PIO2 scanner at 62.67 Hz with
    1/2/4/5 planes, buffer swap at frame start; new Q18 to scope J5.
    - Coil starting values from the ROM captures.
    Claude-Session: https://claude.a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
2026-10-06 docs: Q15, Tron LE scans 4 switch columns; fiber optics are IO aux strobes
    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
2026-10-06 docs: bus header is J9 on the CPU board, GPIO31 memory protect, LTC4412 power mux, J17-J21
    Aligns the architecture doc with the KiCad schematic draft (PR #2).
    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
2026-10-06 docs: prototype uses a standard Pi on the 40-pin header, keeping the Pi's own HDMI
    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
2026-10-06 Add original CPU board connector and mounting-hole positions
    Derived from the vector component-layout page of the manual (520-5246-00
    Rev G), scale calibrated on six standard connector bodies. Adds a CSV of
    every pin and hole, a DXF outline for KiCad, an annotated layout image and
    the script that regenerates them.
    Claude-Session: https://claude.ai/code/session_0155hMZtPEAnktEe3PkJXsS4
    [sam_cpu_520-5246-00_outline.dxf, sam_cpu_520-5246-00_positions.csv]
